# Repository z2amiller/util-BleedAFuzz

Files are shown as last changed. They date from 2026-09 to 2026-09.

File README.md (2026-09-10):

# util-BleedAFuzz

A plug-in NPN transistor that biases like a lower-hFE part. In a
single-transistor fuzz with collector-feedback bias (a large resistor from
collector to base), the transistor's hFE mostly decides the DC collector
voltage, not the gain. So when everyone says a circuit "sounds best with a
125 hFE transistor" and all you have is 300s and 600s, what you actually need
is the collector voltage a 125 would give. This board gets you there with a
trimmer.

## How it works

Q1 is wired straight across the header. A fixed 1M plus a 1M trimmer from base
to emitter bleeds a settable share of the base drive, so the feedback resistor
has to supply more current and the collector rises exactly as it would with a
lower-hFE part. The bleed spans 1M to 2M. Effective hFE at a 50 µA stage:

| Bleed | BC847C (~600) | 2SC1815-GR (~300) |
| ----- | --- | --- |
| 1M | ~80 | ~70 |
| 2M | ~140 | ~110 |

LEAK is an optional 2.2M collector-base resistor that mimics germanium
collector leakage (leave it off unless wanted).

Header order is E, B, C; plug a BC-series (C, B, E) socket in reversed.

## Example: PedalPCB Overcast Fuzz

PedalPCB's [Overcast Fuzz](https://www.pedalpcb.com/product/pcb724/)
([build doc](https://docs.pedalpcb.com/project/OvercastFuzz-PedalPCB.pdf)) is a
Spirit in the Sky style fuzz: one gain transistor with 6M collector-to-base
bias, a 470R emitter resistor and a 100K collector load, and the forum
consensus is that it sounds best around hFE 125. With a 2SC1815-GR (hFE ~300) the
collector sits near 2.0 V; a 125 hFE part would put it near 3.3 V with the
gain control at minimum. Plug this board into the Q1 socket, put a meter on
the collector, and trim until it reads about 3.3 V to nail the 125 hFE sound.

For circuits where the transistor's input impedance matters too (a Fuzz Face
Q1 fed straight from the pickup), the companion
[util-DialAFuzz](https://github.com/z2amiller/util-DialAFuzz) is the better
tool.

## Gerbers

[GERBER-util-BleedAFuzz.zip](GERBER-util-BleedAFuzz.zip) is the JLCPCB-ready
gerber and drill set; no KiCad install needed to order the board. One SOT-23
transistor, two 0805 resistors (one optional), a 3-pin header and a through-hole 1M
trimmer on the back.

## License

Licensed under the **CERN Open Hardware Licence Version 2 – Permissive**
(CERN-OHL-P v2). See [LICENSE](LICENSE) and [NOTICE](NOTICE).

You may make, modify, and sell boards from these files, with no obligation to
publish your changes.

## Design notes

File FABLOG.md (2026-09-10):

# Fab Log

| Date | Board | Rev | Gen | Gerber SHA256 | JLC Order # | Notes |
|---|---|---|---|---|---|---|
| 2026-09-09T19:25 | util-BleedAFuzz | 0.2 | 2 | 0ce55aceb2bc | | |

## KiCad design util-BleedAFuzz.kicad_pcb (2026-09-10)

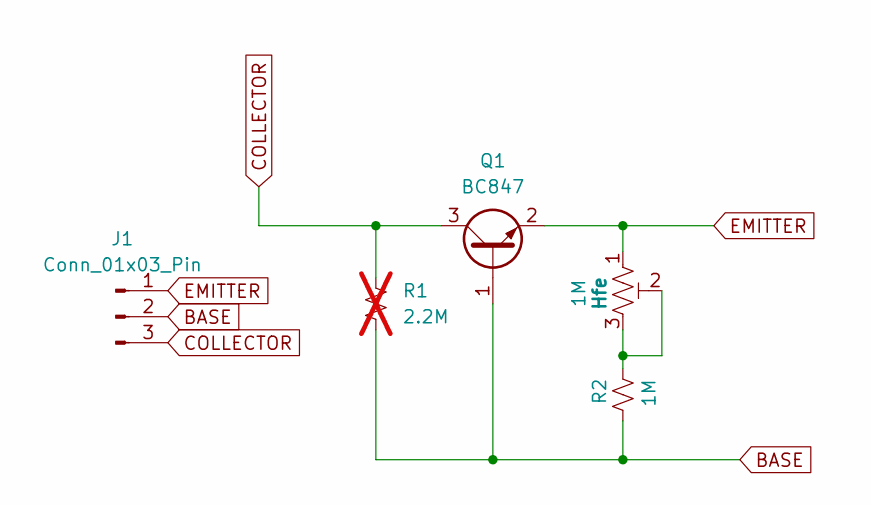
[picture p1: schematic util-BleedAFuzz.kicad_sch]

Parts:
J1: Conn_01x03_Pin; PinHeader_1x03_P2.54mm_Vertical
Q1: BC847; SOT-23_Handsoldering
R1: 2.2M; R_0805_2012Metric_Pad1.20x1.40mm_HandSolder; not fitted
R2: 1M; R_0805_2012Metric_Pad1.20x1.40mm_HandSolder
RV1: 1M; Variable Trimmer

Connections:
BASE: J1.2, Q1.1 (B), R1.1, R2.1
COLLECTOR: J1.3, Q1.3 (C), R1.2
EMITTER: J1.1, Q1.2 (E), RV1.1
unnamed: R2.2, RV1.2, RV1.3

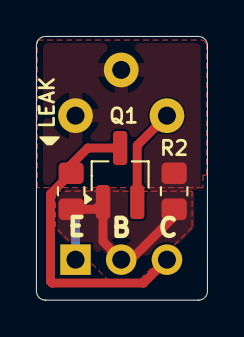
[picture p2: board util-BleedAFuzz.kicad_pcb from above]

Board: 2 copper layers, 9.5 x 14.7 mm, 5 parts (1 on the bottom side), 4 nets.

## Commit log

2026-09-10 Initial commit: cloned from util-DialAFuzz
    [util-BleedAFuzz.kicad_pcb, util-BleedAFuzz.kicad_sch]
2026-09-10 Bleed-a-Fuzz: single transistor with 1M fixed + 1M trimmer base-emitter bleed
    Q1 sits straight across the E-B-C header; R2 1M in series with RV1 1M
    (rheostat) from base to emitter bleeds base drive so the host stage biases
    as if the transistor had a lower hFE (1M..2M covers ~70..140 in a 50 uA
    collector-feedback stage such as the Overcast's Q1, ~190..240 in a
    fuzz-face Q1 slot). R1 2.2M collector-base (DNP) is the leakage stand-in.
    Thermal-relief DRC errors on RV1 pad 1 fixed; silk renamed.
    [util-BleedAFuzz.kicad_pcb, util-BleedAFuzz.kicad_sch]
2026-09-10 Add rev 0.1 gerber zip at the repo root for KiCad-free ordering
    Also carries kicad-jlcpcb-tools' own saves to the board and project.db
    from the generation run.
    [util-BleedAFuzz.kicad_pcb]
2026-09-10 util-BleedAFuzz 0.2 fab outputs (g2)
    [util-BleedAFuzz.kicad_pcb]
2026-09-10 Root gerber zip and README updated to rev 0.2 (g2)
2026-09-10 README: what the board does, how, and a Spirit in the Sky example
2026-09-10 Update README with clearer trimming instructions
    Clarified instructions for trimming the collector voltage to achieve the 125 hFE sound. Updated the description of the Gerber files and components needed.
